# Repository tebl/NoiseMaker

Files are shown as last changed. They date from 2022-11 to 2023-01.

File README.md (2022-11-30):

# NoiseMaker
When I first started out with my somewhat weird hobby of working with seriously to extremely outdated computers, the first things to go were naturally the inevitably failing hard-drives that ended up being replaced by Compact Flash solutions. The second to go were the physical floppy disk drives, having been replaced by Gotek drives. The result, while enjoyable to use, were vintage computers that even the wife could even stand to listen to. Except... that's not good, they're supposed to go *whirr*, *click*, *whine* and rotate grinding gears at such a rate that your significant other simply won't just accept a room dedicated to your vintage computers, they should demand that you get started on building such a room!

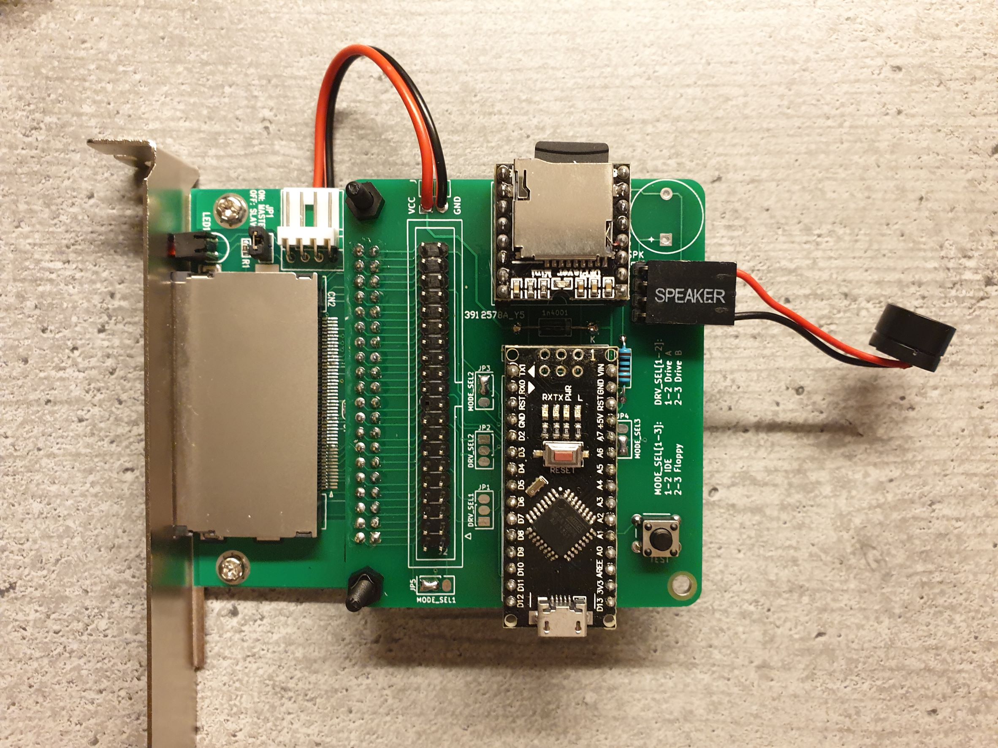
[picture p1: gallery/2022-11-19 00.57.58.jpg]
NoiseMaker Standard, with Compact Flash


Was I going back to the old failiure rate of old mechanical drives? Nope, I followed the tutorials and installed a buzzer kit on that Gotek. Was I happy with it? Not really. So I did what I tend to do, go on AliExpress and ordered a bucketload of Arduino-modules listed as capable of playing back sound files. The cheapest of the bunch by far, was the *MP3-TF-16P* - also commonly known as the *DFPlayer Mini*. The very next thing that I discovered was that I didn't really understand enough about the various signals used to communicate with floppy disk drives, so they all sat in box somewhere until someone created something called *HDD Clicker*. I saw the videos made about it, but I wanted more options and so I started tinkering with the modules again - especially with the realization of how simple an IDE-version could have been made if I had just started there instead.

The result was this project, an amalgamation of the cheapest hardware in an oversized package that somehow probably ends up costing several times more to build than the popular thing. I could certainly have gone for more compact or powerful options, but it was an excuse to use some  Arduino Nano boards "powered" by ATmega168, which I had accidentally ordered a couple of years ago and never got around to throwing out.

- [1> Modules](#1-modules)
  - [1.1> NoiseMaker Standard](#11-noisemaker-standard)
- [3> Acknowledgements](#3-acknowledgements)

# 1> Modules
The following modules have been provided as part of this project. While more modules may have been included as part of this repository, these are the ones that I have actually built and tested. As mentioned in the relevant license for this project - that's not a warranty, just an indication that it worked that one time I tried it with my particular setup.

| Module | Description |
| --- | --- |
| [NoiseMaker Standard](#11-noisemaker-standard) | Standard Arduino-based *NoiseMaker*, supporting 34-pin floppy and 40-pin IDE.

## 1.1> NoiseMaker Standard
This is the standard version of the *NoiseMaker*, created as a carrier board for both the *MP3-TF-16P* and an Arduino Nano. It can be built to work directly with IDE-devices, adding a female 40-pin header to the bottom of the card it can also be attached directly onto common *Compact Flash to IDE*-module. It can also be used in the "middle" of the cable, or just plugged into an unused part of the cable. The Arduino unfortunately doesn't have anywhere near the capability needed to actually interpret the communication between the devices, it is only responding to the same signal that your motherboard would normally read in order to light up your *HDD LED* (if you have one). 

Compact Flash

 Alternatively you can build the device for use with 34-pin floppy drive replacements such as the Gotek instead. Similarly as with the IDE-version, it can also be plugged into an unused connector on your cable or in-between your drive and motherboard. Note that since the 34-pin cables have a twist on it, you need to set the *DRV_SEL* to the opposite value if connecting it up by itself after the twist.

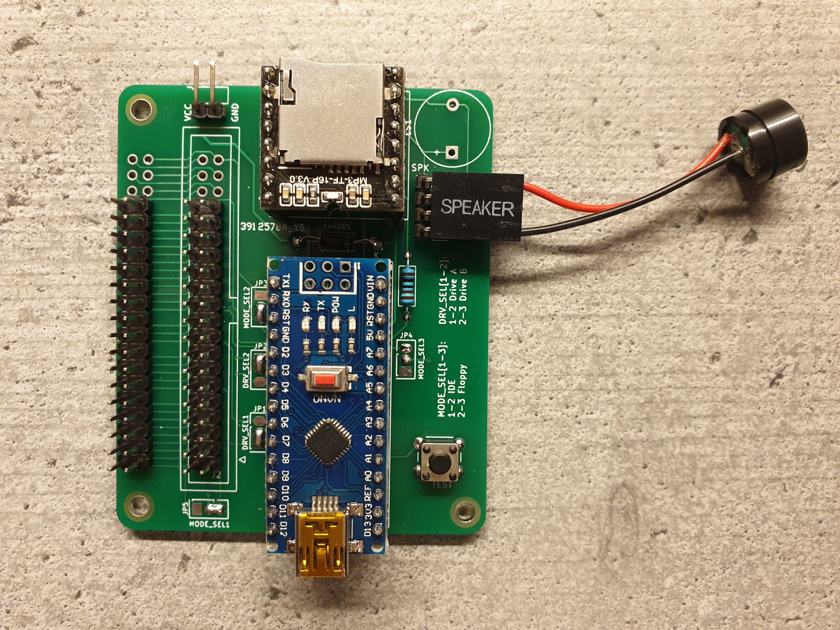
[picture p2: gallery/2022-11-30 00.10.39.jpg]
Floppy Interface


The documentation belonging to different variations of the standard NoiseMaker have been listed below, click the name for build documentation or follow the documentation links to jump to different sections within it. Ideally all of them should support being built as a NoiseMaker for either floppy or IDE, but not both at the same time (for that you will need two separate copies of the PCB).

| Module | Description | Documentation | Order |
| --- | --- | --- | --- |
| [NoiseMaker](https://github.com/tebl/NoiseMaker/tree/main/NoiseMaker) | Arduino Nano, MP3-TF-16P | [Documentation](https://github.com/tebl/NoiseMaker/tree/main/NoiseMaker), [BOM](https://github.com/tebl/NoiseMaker/blob/main/NoiseMaker/README.md#3-bom), [Setting it up](https://github.com/tebl/NoiseMaker/blob/main/documentation/setting_it_up.md), [Getting started](https://github.com/tebl/NoiseMaker/blob/main/documentation/getting_started.md) | PCBWay

# 3> Acknowledgements
Everything comes from something, in particular when it comes to most of my electronics projects. I mainly build things I would like to own, often doing a respin to fit my own particular style and preferences. As mentioned I originally started making a module for making noise when used with modern floppy drive replacements, but it was only with inspiration from seeing the *HDD Clicker* that I went back and actually finished building it.

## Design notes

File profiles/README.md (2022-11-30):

# 1> Profiles
The *NoiseMaker* simply plays audio files using a cheaply available module for Arduino, oftenly referred to as the *DFPlayer Mini* though the name *MP3-tf-16p* will probably be more correct. The Arduino sketch included as part of the *NoiseMaker* refers to different sets of audio files as *"profiles"* - the contents of the subdirectory called "sdcard" must be copied onto the SD-card used.

While I hope to make my own recordings to match my own hardware, a few profiles have been created using resources found online. As such they have their own terms for usage and so this file should include all of the information needed to comply with the license that they have been made available under. If you find something to be missing, let me know and I'll endevour to either update or have those specific files removed.

- Floppy
  - [01> Amiga Floppy Disk](#01-amiga-floppy)
- IDE
  - [10> IBM Deskstar 22GXP 7200](#old-hdds)
  - [11> WD Caviar BB 7200](#old-hdds)
  - [12> Seagate Medalist ST34321A 5400](#old-hdds)
  - [13> IBM UltraStar ES 5400](#old-hdds)
  - [14> Maxtor Atlas 10k](#old-hdds)

# 01> Amiga Floppy Disk
Modified versions of Amiga floppy drive sounds, the original audio files have been up for download as part of the [WinUAE](https://www.winuae.net/download/) installation.

# Old HDDs
User [Klerpp](https://freesound.org/people/Klerrp/) on freesound has created a pack of recordings of [old HDDs](https://freesound.org/people/Klerrp/packs/8850), this profile has been created with those recordings as a starting point. The files have been tweaked for length, volume and separated into separate files depending on what the HDD was doing at the time.

The files have been release under a [CC0 1.0-license](https://creativecommons.org/publicdomain/zero/1.0/), requiring no specific licensing steps beyond specifying that they come with no warranty of any kind - neither from its original creator or the NoiseMaker project.

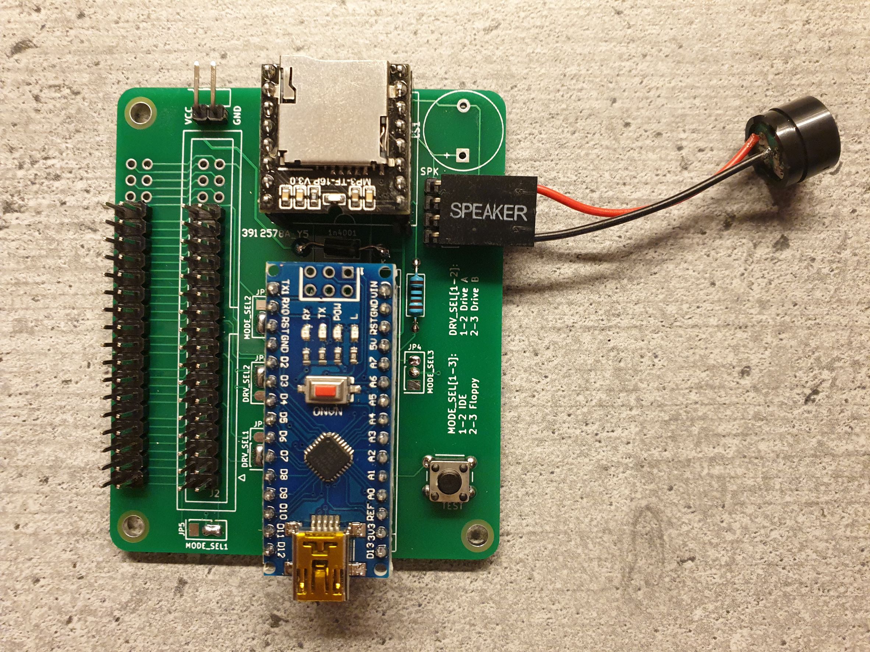
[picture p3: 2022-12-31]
gallery/2022-11-30 00.10.43.jpg

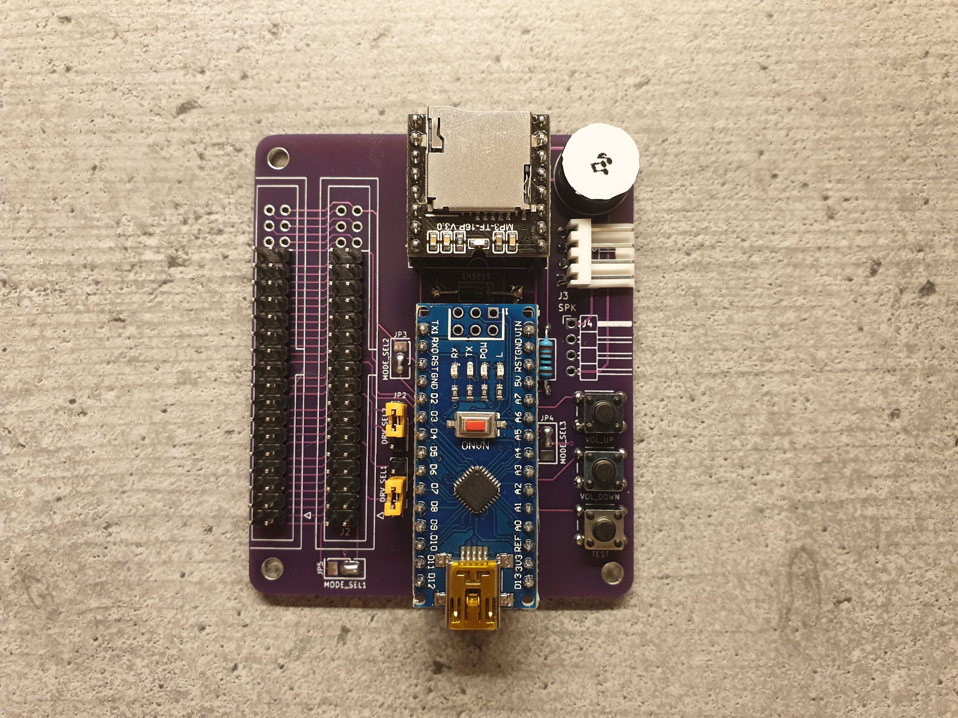
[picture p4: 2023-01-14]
gallery/2023-01-14 02.06.26.jpg

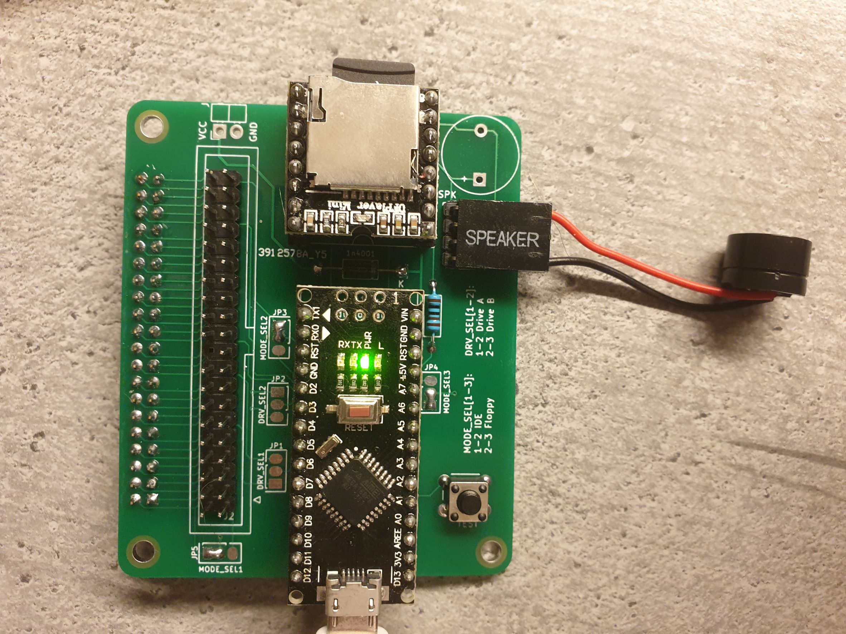
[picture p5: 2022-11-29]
gallery/2022-11-07 00.37.02.jpg

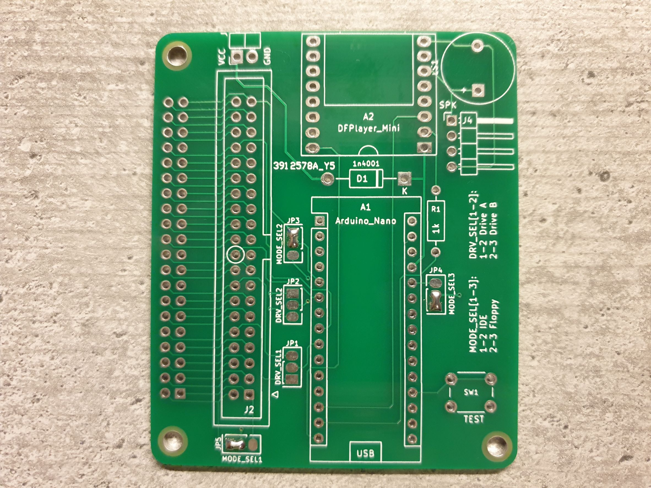
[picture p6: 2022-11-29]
gallery/2022-11-01 23.43.35.jpg

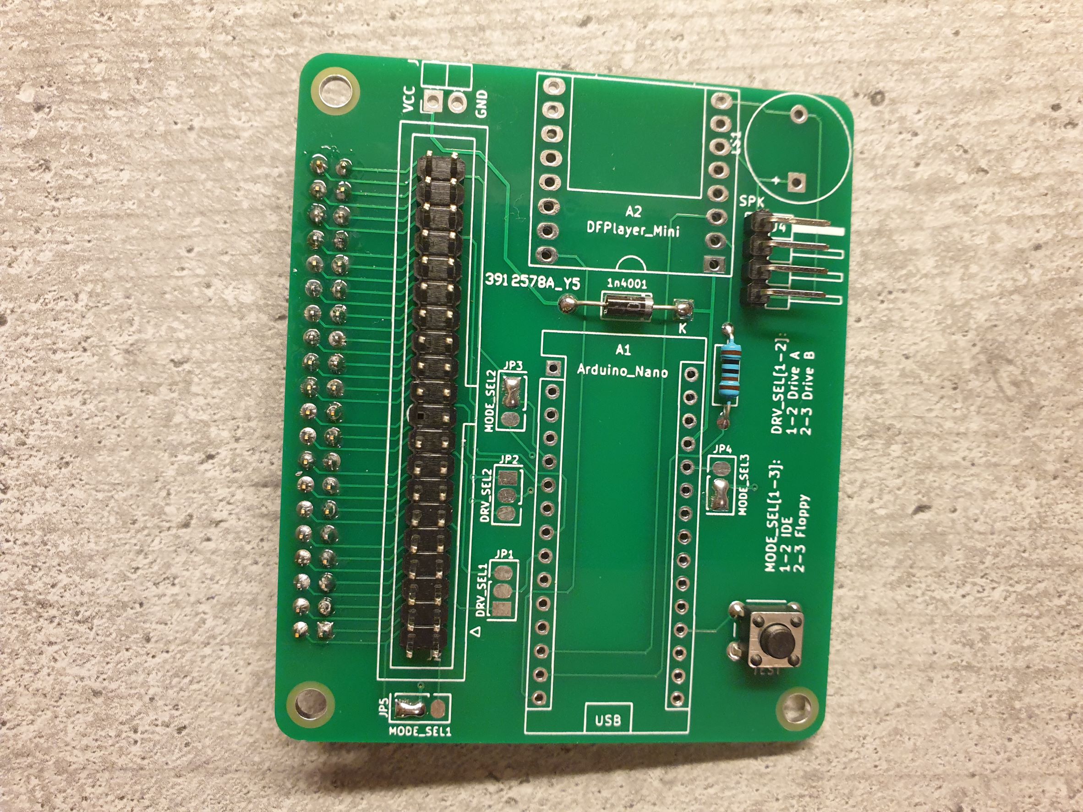
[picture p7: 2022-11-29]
gallery/2022-11-02 00.21.22.jpg

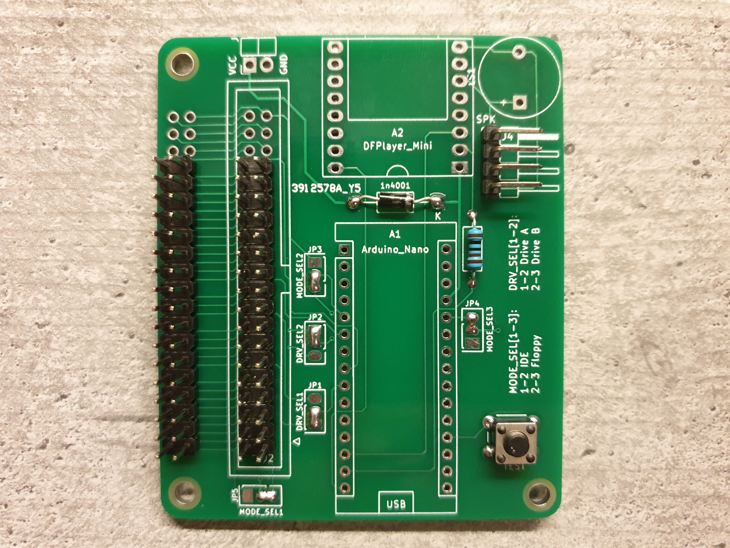
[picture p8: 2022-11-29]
gallery/2022-11-02 00.21.31.jpg

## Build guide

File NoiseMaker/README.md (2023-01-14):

# NoiseMaker Standard
The *NoiseMaker Standard*-version is really the first version I created for making noise when used with either 34-pin floppy drive replacements such as the Gotek - OR - the 40-pin IDE-replacements such as CF2IDE, SD2IDE etc. This document goes into building up a PCB for one of these, but not both at a time. For a more graceful introduction to what the *NoiseMaker* is meant to do, check out the main [documentation](https://github.com/tebl/NoiseMaker) before continuing.

- [1> Building the device](#1-building-the-device)
  - [1.1> Soldering it together](#11-soldering-it-together)
  - [1.2> IDE-version](#12-ide-version)
  - [1.3> Floppy-version](#13-floppy-version)
  - [1.4> Finishing touches](#14-finishing-touches)
- [2> Schematic](#2-schematic)
- [3> BOM](#3-bom)

# 1> Building the device
Building a device such as this assumes you have at least minor experience soldering things together, recommended is that you at the very least have access to a soldering station with adjustable temperature. If currently available, you should probably start with 60/40 rosin core solder as the lead-free alternatives tends to be a bit harder to work with.

With the requirements for basic equipment sorted, we need to talk a bit about what you want to achieve while building this project. The reason I ask is that as already mentioned, you need to pick between Floppy and IDE for each PCB you are building up, mainly because there are physical differences in how each of them connect to the your system. 

Now that you know what you want to build, we can get started on the most expensive step in any build process - shopping! So, head on over to the [BOM](#3-bom)-section for some information on what kind of components that you'll need. While I would have liked to give you specific part numbers for "reputable" electronic part suppliers, I can't afford to shop there so I usually make due with what I can find on sites such as ebay, AliExpress and any similar sites that sell cheap Chinese components. The downside to this is that I can't link to a part directly and expect it to stay listed, so you'll need to consider the description listed as a suggested *search term*.

## 1.1> Soldering it together
The construction of this unit should be fairly straight-forward, just take your time in order to make sure everything goes into place - more or less straight. I usually recommend starting by having a good look at the PCBs, then try to figure out where all of the listed components go and in which orientation they go in (all of this should be clearly marked on the silkscreen). There are no overlapping footprints and though doing it in the wrong order might make it a bit more fiddly to put together, there aren't really all that many issues you can run into as long as you're clear on which interface you're building it for (IDE or floppy). 

## 1.2> IDE-version
I've created a video that goes into whatever details you might need when assembling one for use with IDE, this one specificly was built to mount directly onto a common *Compact Flash*-adapter and for that reason I solder the power wires directly to it instead of using an additional floppy power connector from the systems PSU.

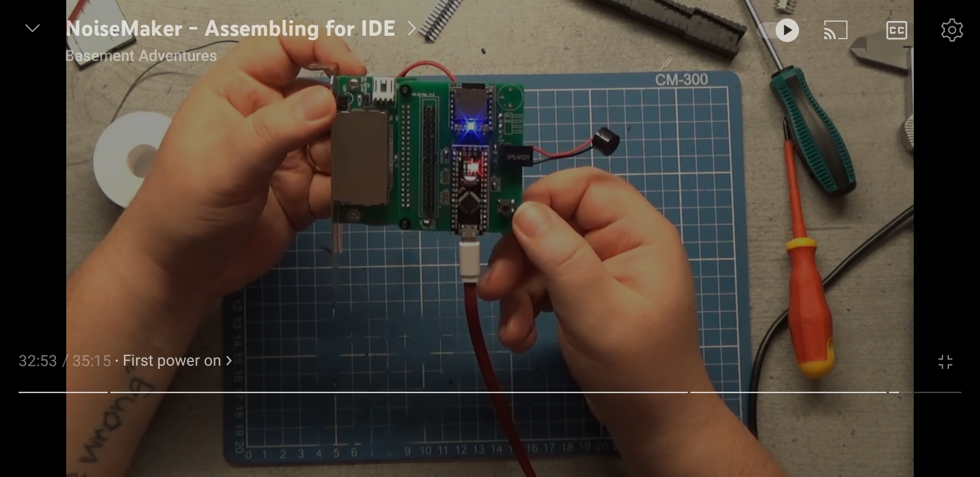
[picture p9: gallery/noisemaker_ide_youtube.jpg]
YouTube image (https://youtu.be/f5QjovpGp8M)


## 1.3> Floppy-version
For now I recommend that you check the build details for the IDE-version, it is mostly the same except for the use of 34-pin Interface.

## 1.4> Finishing touches
Unless one was provided to you by a kit-maker, you will more than likely not have the correct firmware installed on your Arduino Nano. The code you need can be found as part of this repository on the URL [software/arduino/NoiseMaker](https://github.com/tebl/NoiseMaker/tree/main/software/arduino/NoiseMaker), you will need to download a copy of this repository - this is done by using the green button on the [main page](https://github.com/tebl/NoiseMaker) of this repository. You will need to install a couple of libraries in order for the code to compile, the [README](https://github.com/tebl/NoiseMaker/blob/main/software/arduino/NoiseMaker/README.md) contains links to both of these though the preferable way of installing these is probably via your Arduino development environment. The files provided should be suitable for use with both Arduino Studio as well as PlatformIO.

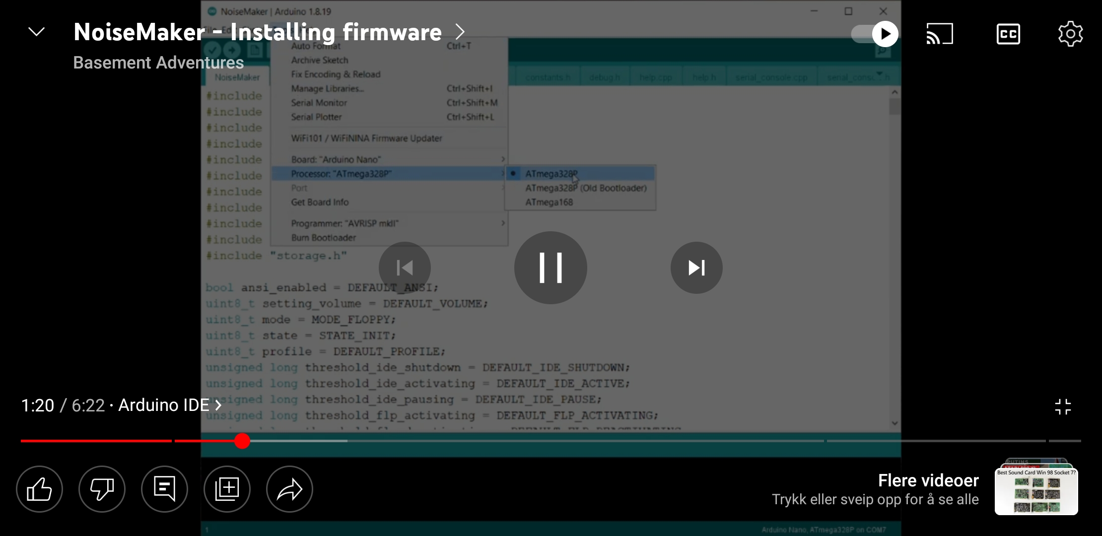
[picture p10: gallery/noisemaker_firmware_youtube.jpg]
YouTube image (https://www.youtube.com/watch?v=h_lniixsJmM)


For Arduino Studio, open the sketch and then select the board that you have (Arduino Nano of some kind). Install the two libraries from *Tools* --> *Manage libraries...* - search for and install the two listed as *ezbutton* as well as *DFRobotDFPlayerMini*. Check that the code now compiles, select the serial port corresponding to your module and upload the sketch.

PlatformIO should handle dependencies somewhat automatically, though I find that in practice we need to run a command for it to happen. Open up a new PlatformIO Terminal (not PowerShell, it's probably the last icon on your bottom toolbar), then run the command *"pio pkg install"*, and it should download and install the latest version of the libraries needed. Ensure that the environment selected on the bottom toolbar corresponds to the board you are using, you may need to edit *platformio.ini* if neither of the combinations is correct for you. Compile and upload the code.

Using a serial terminal connected to the Arduino Nano, you may configure the device according to your preferences. It is recommended to use an ATmega328-based Arduino Nano when you are familiarizing yourself with the commands, as among other commands the *help* command is not available on the ATmega168. When satisfied with any changes, enter the command *save* to store them permanently to the onboard EEPROM. For more detailed information as well as serving as a reference when used with ATmega168, see [Serial Interface](https://github.com/tebl/NoiseMaker/blob/main/documentation/serial_interface.md).

# 2> Schematic
The supplied KiCad files should be sufficient as both a schematic and as a  starting point for ordering PCBs (basically you could just zip the contents of the export folder and upload that on a fabrication site), the schematic is also available in [PDF-format](https://github.com/tebl/NoiseMaker/tree/main/documentation/schematic) and this is what you'll need to print and work your way through this things don't work as expected after assembly.

# 3> BOM
Most parts should be easy to get a hold of from your favourite local electronic component shop, but given that I don't have access to such shops where I live so everything was based on whatever I could get cheapest from eBay/AliExpress (free shipping, but plan on waiting 3-4 weeks for delivery). Components in parenthesis can be considered optional for features beyond the more basic functionality, but where's the fun in that? You probably want the complete package.

| Reference | Item | Count | Order  |
| --- | --- | ----- | --- |
| NoiseMaker Standard | Fabricate using Gerber files | 1 | [PCBWay](https://www.pcbway.com/project/shareproject/NoiseMaker_IDE_Floppy_8a4ab037.html)
| A1 * | Arduino Nano (328, 168 with less features) | 1 |
| A2 * | MP3-TF-16P (also known as DFPlayer Mini) | 1 |
| D1 | 1N5819 (DO-41), 1N4001 if you don't have one available | 1 |
| J1 ** | 2x20pin female header, 2x20pin male header or 2x17pin male header | 1 |
| J2 ** | 2x20pin male header or 2x17pin male header | 1 |
| J3 *** | JVC Mini 4P, right-angle flat power connector for floppy | 1 |
| J4 | 4pin breakable right-angle header | (1)|
| JP1, JP2 | 3pin straight pin header | 2 |
| | Jumper cap | 2 |
| LS1 | Passive buzzer (7.62mm pin spacing) | (1)|
| R1 | 1k Ohm resistor | 1 |
| SW1-SW3 | 6x6mm momentary button | (3)|

*) Both of the modules will be soldered to the PCB with some straight male headers in between, when assembling the first unit it is recommend that you assemble it with female pin headers on the board so that modules can be moved around until happy with the results.

**) The type of header used here depends on what the board will be used as, 2x16pin are for floppy while 2x20pin are for IDE.

***) When installed directly on top of a Compact Flash adapter you can opt to wire it directly to the adapter. If you can't find the connector, it might be easier to find a floppy power splitter cable, cut and solder on the wires from that.

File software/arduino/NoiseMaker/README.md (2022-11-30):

# NoiseMaker

The functionality of the *NoiseMaker* has been realized using what for all purposes can be considered the least common denominator when it comes to MCUs, the standard ATmega328-based *Arduino Nano*. Due to an accidental order a couple years back I ended up with a handful of boards even more limited than these ones, based on the ATmega168 instead - offering half of the RAM and flash space expected - in order to get some usage out of them there is the option of using these lower capacity chips as well. This does however come at the cost of some nice-to-have features, but beyond being slightly less configurable on-the-fly using the serial interface - you should be able to enjoy it just the same once things are properly set up.

Consider editing *settings.h* to your liking instead of relying on run-time configuration, if you already have a preference for the values you want to use in the end. For either version of board, just make sure that you've correctly specified the chip used - before compiling the code.

## Libraries

While the installation of libraries should be handled automatically when using PlatformIO from within Visual Studio Code, but I recognize that many will simply want to get the code onto the board while using the standard *Arduino IDE* instead. In that case you may need to install libraries manually, the ones that are currently needed are as follows:

- [DFRobotDFPlayerMini](https://github.com/DFRobot/DFRobotDFPlayerMini)
- [ezButton](https://github.com/ArduinoGetStarted/button)

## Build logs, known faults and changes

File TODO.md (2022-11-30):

# TODO
- NoiseMaker Standard
- NoiseMaker Mini
  - Create a smaller version of the board, with wire-pads instead of full 34-pin or 40-pin connectors.

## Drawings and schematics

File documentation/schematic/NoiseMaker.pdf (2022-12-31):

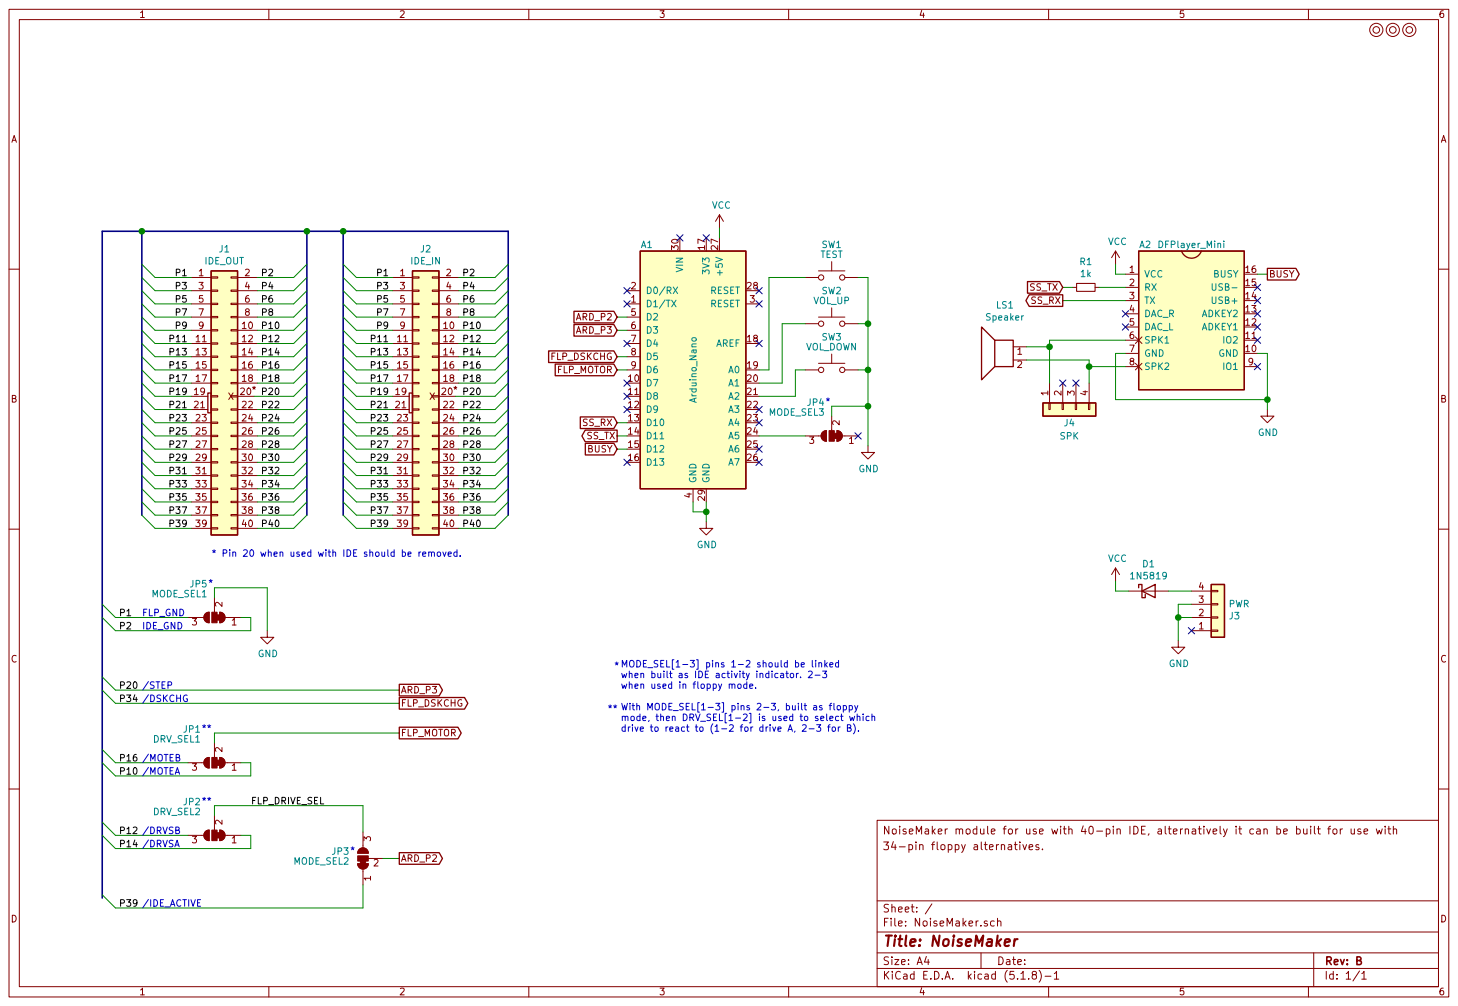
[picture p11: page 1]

* Pin 20 when used with IDE should be removed.

* MODE_SEL[1-3] pins 1-2 should be linked
when built as IDE activity indicator. 2-3
when used in floppy mode.

drive to react to (1-2 for drive A, 2-3 for B). **
mode, then DRV_SEL[1-2] is used to select which

NoiseMaker module for use with 40-pin IDE, alternatively it can be built for use with
Id: 1/1 Title: NoiseMaker File: NoiseMaker.sch Sheet: / 34-pin floppy alternatives.

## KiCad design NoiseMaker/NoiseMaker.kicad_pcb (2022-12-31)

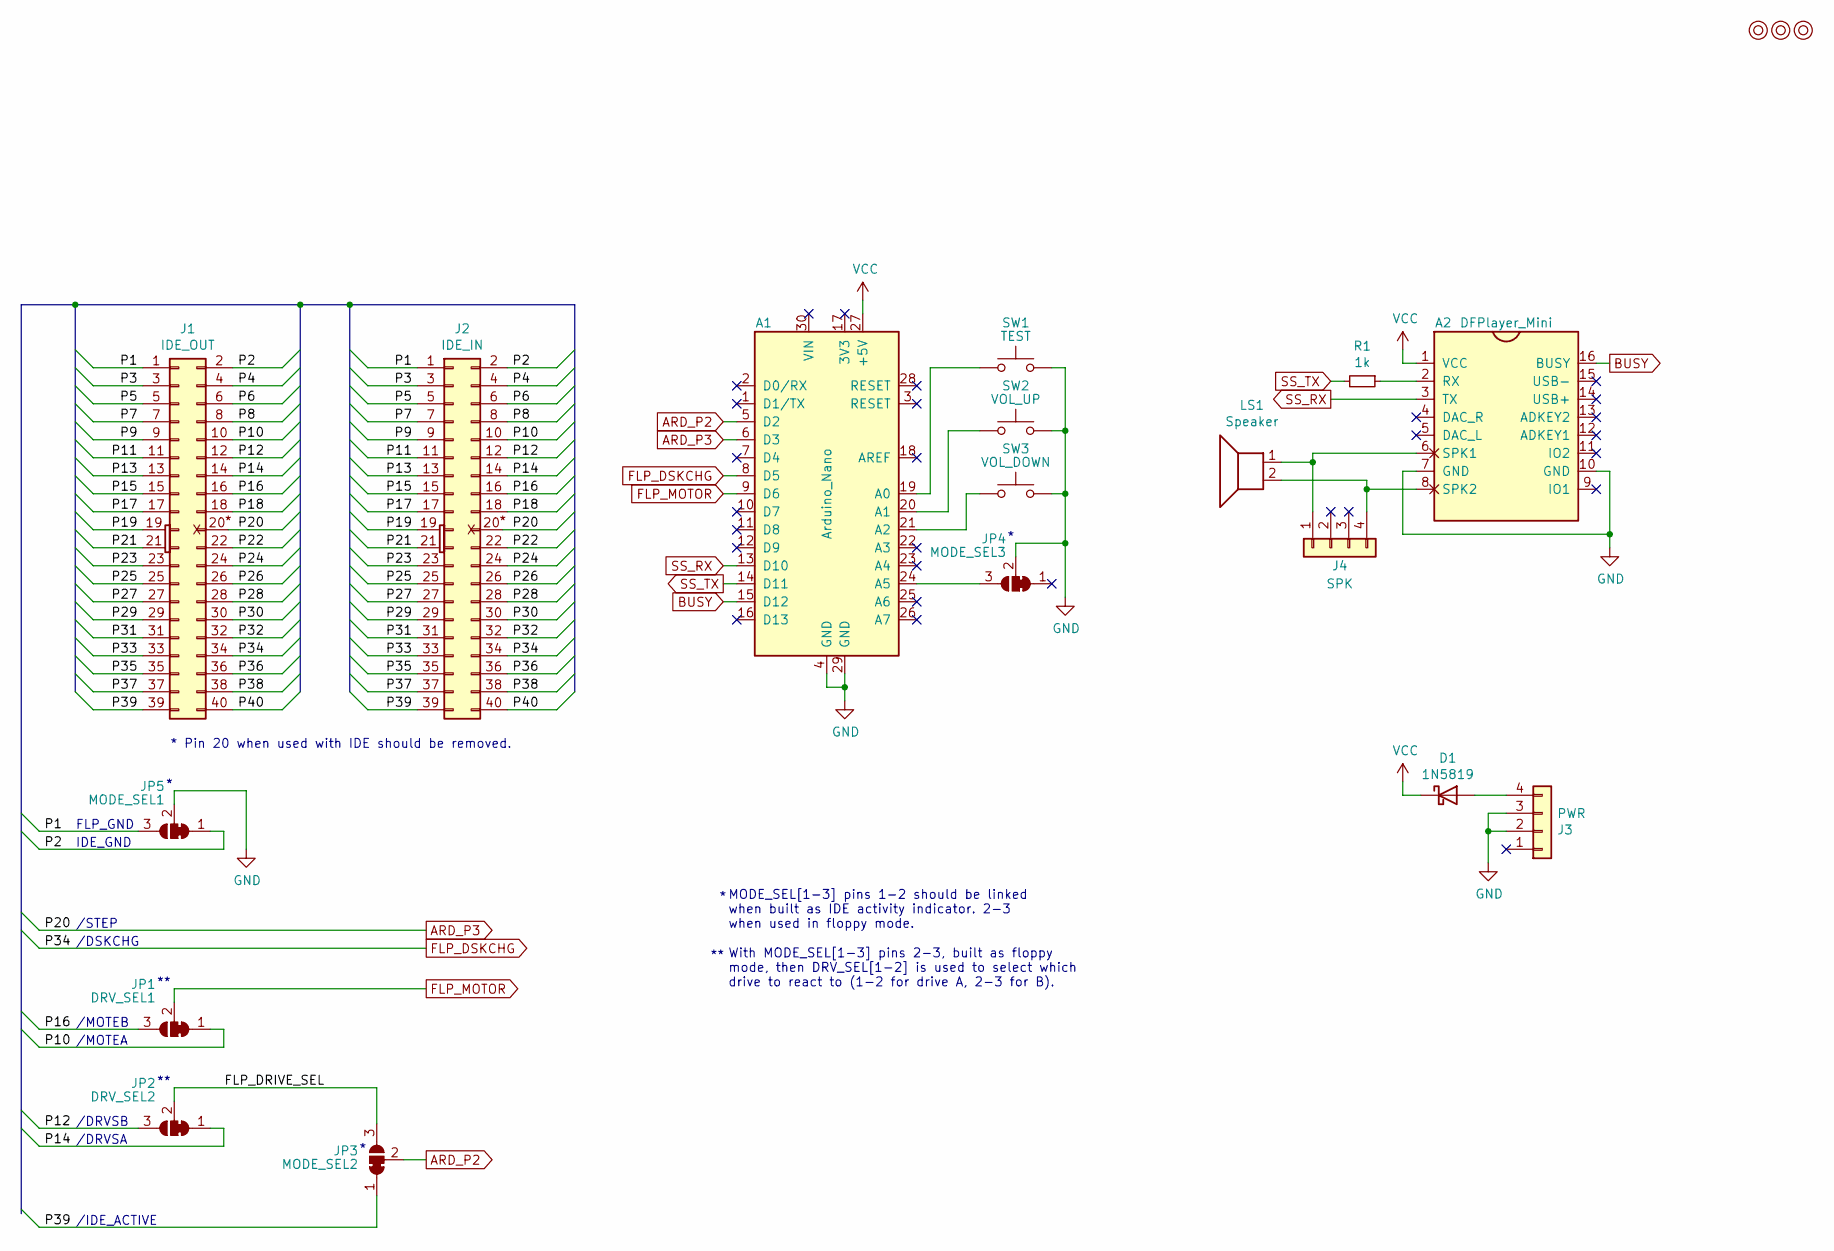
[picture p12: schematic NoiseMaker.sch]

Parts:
A1: Arduino_Nano
A2: DFPlayer_Mini
D1: 1N5819; D_DO-41_SOD81_P12.70mm_Horizontal
J1: IDE_OUT; PinSocket_2x20_P2.54mm_Vertical
J2: IDE_IN; IDC-Header_2x20_P2.54mm_Vertical
J3: PWR; Molex_KK-254_1x04_P2.54mm_Horizontal
J4: SPK; PinHeader_1x04_P2.54mm_Horizontal
JP1: DRV_SEL1; PinHeader_1x03_P2.54mm_Vertical
JP2: DRV_SEL2; PinHeader_1x03_P2.54mm_Vertical
JP3: MODE_SEL2; select2
JP4: MODE_SEL3; select2
JP5: MODE_SEL1; select2
LS1: Speaker; Buzzer_12x9.5RM7.6
M1, M2, M3: Mounting; M3_pin
R1: 1k; R_Axial_DIN0207_L6.3mm_D2.5mm_P10.16mm_Horizontal
SW1: TEST; SW_PUSH_6mm
SW2: VOL_UP; SW_PUSH_6mm
SW3: VOL_DOWN; SW_PUSH_6mm

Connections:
/FLP_DRIVE_SEL: JP2.2 (C), JP3.3 (B)
/P1: J1.1, J2.1, JP5.3 (B)
/P2: J1.2, J2.2, JP5.1 (A)
/P3: J1.3, J2.3
/P4: J1.4, J2.4
/P5: J1.5, J2.5
/P6: J1.6, J2.6
/P7: J1.7, J2.7
/P8: J1.8, J2.8
/P9: J1.9, J2.9
/P10: J1.10, J2.10, JP1.1 (A)
/P11: J1.11, J2.11
/P12: J1.12, J2.12, JP2.3 (B)
/P13: J1.13, J2.13
/P14: J1.14, J2.14, JP2.1 (A)
/P15: J1.15, J2.15
/P16: J1.16, J2.16, JP1.3 (B)
/P17: J1.17, J2.17
/P18: J1.18, J2.18
/P19: J1.19, J2.19
/P21: J1.21, J2.21
/P22: J1.22, J2.22
/P23: J1.23, J2.23
/P24: J1.24, J2.24
/P25: J1.25, J2.25
/P26: J1.26, J2.26
/P27: J1.27, J2.27
/P28: J1.28, J2.28
/P29: J1.29, J2.29
/P30: J1.30, J2.30
/P31: J1.31, J2.31
/P32: J1.32, J2.32
/P33: J1.33, J2.33
/P35: J1.35, J2.35
/P36: J1.36, J2.36
/P37: J1.37, J2.37
/P38: J1.38, J2.38
/P39: J1.39, J2.39, JP3.1 (A)
/P40: J1.40, J2.40
ARD_P2: A1.5 (D2), JP3.2 (C)
ARD_P3: A1.6 (D3), J1.20, J2.20
BUSY: A1.15 (D12), A2.16 (BUSY)
FLP_DSKCHG: A1.8 (D5), J1.34, J2.34
FLP_MOTOR: A1.9 (D6), JP1.2 (C)
GND: A1.4 (GND), A1.29 (GND), A2.7 (GND), A2.10 (GND), J3.2, J3.3, JP4.2 (C), JP5.2 (C), SW1.2, SW2.2, SW3.2
unnamed: A1.19 (A0), SW1.1
unnamed: A1.20 (A1), SW2.1
unnamed: A1.21 (A2), SW3.1
unnamed: A1.24 (A5), JP4.3 (B)
unnamed: A2.2 (RX), R1.1
unnamed: A2.6 (SPK1), J4.1, LS1.1
unnamed: A2.8 (SPK2), J4.4, LS1.2
unnamed: D1.2 (A), J3.4
SS_RX: A1.13 (D10), A2.3 (TX)
SS_TX: A1.14 (D11), R1.2
VCC: A1.27 (+5V), A2.1 (VCC), D1.1 (K)

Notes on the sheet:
/DRVSA
/DRVSB
/MOTEA
/MOTEB
/IDE_ACTIVE
/STEP
/DSKCHG
* Pin 20 when used with IDE should be removed.
IDE_GND
FLP_GND
MODE_SEL[1-3] pins 1-2 should be linked when built as IDE activity indicator. 2-3 when used in floppy mode.
With MODE_SEL[1-3] pins 2-3, built as floppy mode, then DRV_SEL[1-2] is used to select which drive to react to (1-2 for drive A, 2-3 for B).

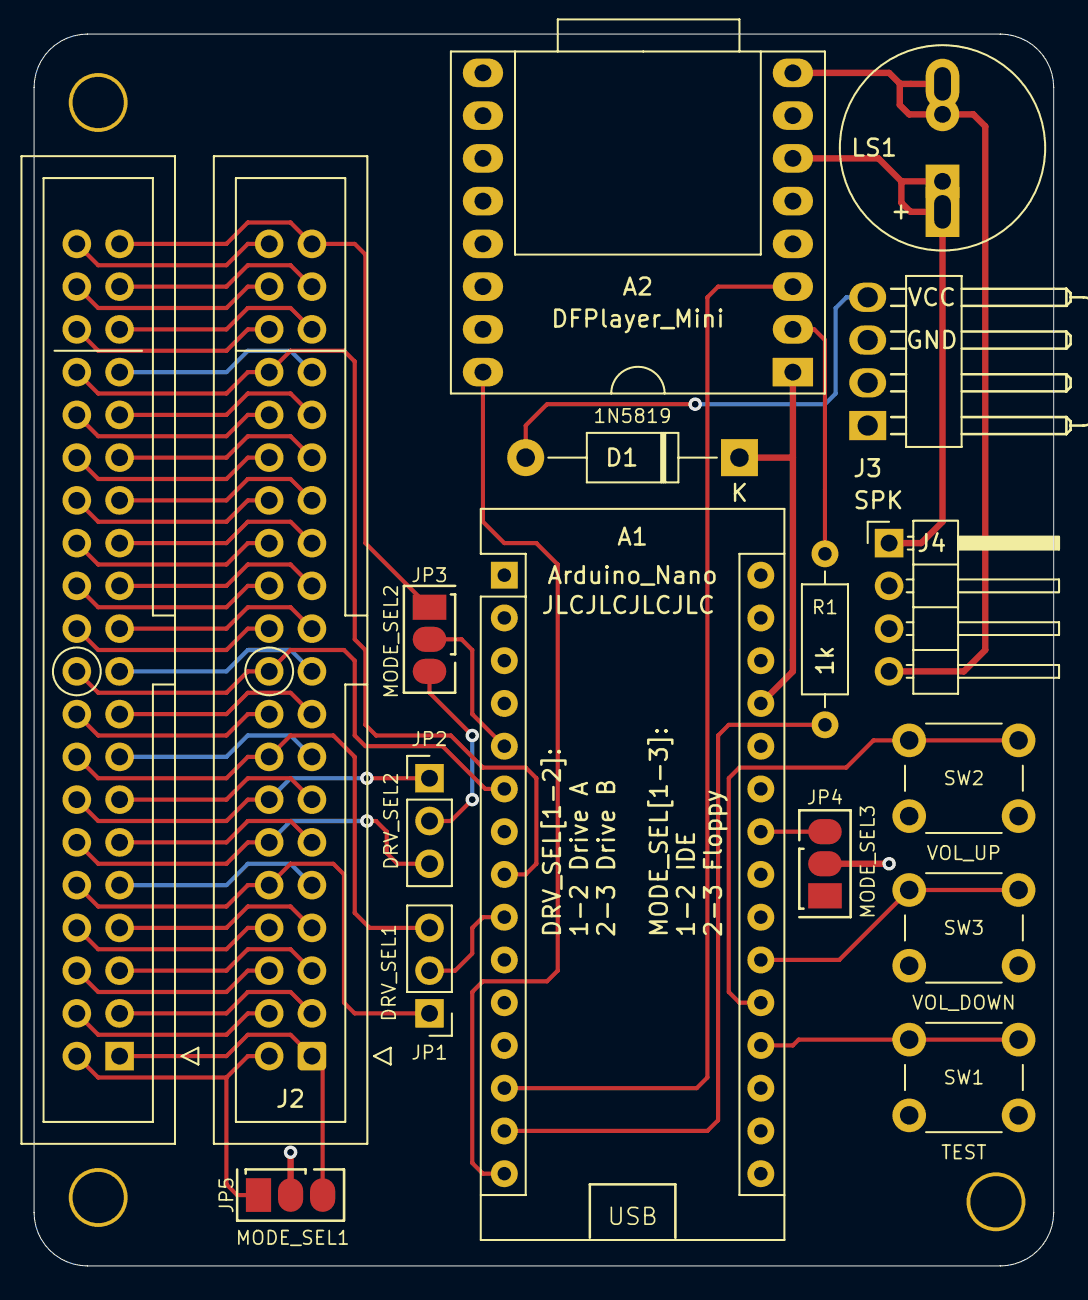
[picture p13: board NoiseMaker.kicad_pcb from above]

Board: 2 copper layers, 60.6 x 73.2 mm, 20 parts (1 on the bottom side), 56 nets.

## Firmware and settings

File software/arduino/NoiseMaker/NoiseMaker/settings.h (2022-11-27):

#pragma once
#include "constants.h"
// #define DEBUG
// #define DEBUG_VERBOSE
// #define DEBUG_OFFLINE

#define DEFAULT_IDE_SHUTDOWN TEN_MINUTES
#define DEFAULT_IDE_ACTIVE 100
#define DEFAULT_IDE_PAUSE 250
#define DEFAULT_FLP_ACTIVATING 500
#define DEFAULT_FLP_DEACTIVATING 750

#define DEFAULT_VOLUME 15
#define DEFAULT_ANSI false
#define DEFAULT_PROFILE 0

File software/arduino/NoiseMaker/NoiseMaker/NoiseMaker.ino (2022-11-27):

#include <Arduino.h>
#include <ezButton.h>
#include <SoftwareSerial.h>
#include <DFRobotDFPlayerMini.h>
#include "constants.h"
#include "settings.h"
#include "debug.h"
#include "serial_console.h"
#include "commands.h"
#include "ansi.h"
#include "storage.h"

bool ansi_enabled = DEFAULT_ANSI;
uint8_t setting_volume = DEFAULT_VOLUME;
uint8_t mode = MODE_FLOPPY;
uint8_t state = STATE_INIT;
uint8_t profile = DEFAULT_PROFILE;
unsigned long threshold_ide_shutdown = DEFAULT_IDE_SHUTDOWN;
unsigned long threshold_ide_activating = DEFAULT_IDE_ACTIVE;
unsigned long threshold_ide_pausing = DEFAULT_IDE_PAUSE;
unsigned long threshold_flp_activating = DEFAULT_FLP_ACTIVATING;
unsigned long threshold_flp_deactivating = DEFAULT_FLP_DEACTIVATING;

SoftwareSerial dfplayer_serial(DFPlayer_RX, DFPlayer_TX);
DFRobotDFPlayerMini dfplayer;
ezButton vol_up(PIN_VOL_UP);
ezButton vol_down(PIN_VOL_DOWN);

volatile unsigned long last_activity = 0;
bool last_motor_on = false;
uint8_t last_error;
bool replay = false;

void play_flp_startup() {
  dfplayer.playFolder(OFFSET_FLOPPY + profile, SOUND_FLP_STARTUP);
}

void play_flp_spin() {
  dfplayer.playFolder(OFFSET_FLOPPY + profile, SOUND_FLP_SPIN);
}

void play_flp_snatch() {
  dfplayer.playFolder(OFFSET_FLOPPY + profile, SOUND_FLP_SNATCH);
}

void play_flp_click() {
  dfplayer.advertise(OFFSET_FLOPPY + profile);
}

void flp_interrupt_step() {
  // if (digitalRead(PIN_FLP_DRIVE_SEL) == LOW) {
    last_activity = millis();
  // }
}

void setup_floppy() {
  uint8_t mode = INPUT;
  #ifdef DEBUG_OFFLINE
    mode = INPUT_PULLUP;
  #endif
  pinMode(PIN_FLP_DRIVE_SEL, mode);
  pinMode(PIN_FLP_STEP, mode);
  pinMode(PIN_FLP_DISK_CHANGE, mode);
  pinMode(PIN_FLP_MOTOR_EN, mode);

  play_flp_startup();
  attachInterrupt(digitalPinToInterrupt(PIN_FLP_STEP), flp_interrupt_step, FALLING);
}

void play_ide_startup() {
  dfplayer.playFolder(OFFSET_IDE + profile, SOUND_IDE_STARTUP);
}

void play_ide_active() {
  dfplayer.playFolder(OFFSET_IDE + profile, SOUND_IDE_ACTIVE);
}

void play_ide_shutdown() {
  dfplayer.playFolder(OFFSET_IDE + profile, SOUND_IDE_SHUTDOWN);
}

void ide_interrupt() {
  last_activity = millis();
}

void setup_ide() {
  uint8_t mode = INPUT;
  #ifdef DEBUG_OFFLINE
    mode = INPUT_PULLUP;
  #endif
  pinMode(PIN_IDE_ACTIVE, mode);

  play_ide_startup();
  attachInterrupt(digitalPinToInterrupt(PIN_IDE_ACTIVE), ide_interrupt, FALLING);
}

void loop_floppy() {
  switch (state) {
    /* Waiting for startup sound to finish */
    case STATE_INIT:
      while (dfplayer.available()) {
        last_error = dfplayer.readType(); 
        if (last_error == DFPlayerPlayFinished) {
          delay(100);
          DEBUG_PRINTLN(F("set idle"));
          state = STATE_FLP_IDLE;
        } else unknown_error(last_error, dfplayer.read());
      }
      break;

    /* Waiting for activity */
    case STATE_FLP_IDLE:
      while (digitalRead(DFPlayer_BUSY) == LOW) DEBUG_SPINLOCK('-');
      if (digitalRead(PIN_FLP_MOTOR_EN) == LOW) {
        DEBUG_PRINTLN(F("motor on"));
        state = STATE_FLP_SPINNING;
        play_flp_spin();
      }
      break;
    
    /* Motor is spinning, wait for steps */
    case STATE_FLP_SPINNING:
      replay = false;
      if (digitalRead(PIN_FLP_MOTOR_EN) == HIGH) {
        DEBUG_PRINTLN(F("motor off"));
        state = STATE_FLP_IDLE;
        dfplayer.stop();
        while (digitalRead(DFPlayer_BUSY) == LOW) DEBUG_SPINLOCK('.');
      } else {
        while (dfplayer.available()) {
          last_error = dfplayer.readType(); 
          if (last_error == DFPlayerPlayFinished) {
            replay = true;
          } else unknown_error(last_error, dfplayer.read());
        }

        if (replay) {
            DEBUG_PRINTLN(F("replay spin"));
            play_flp_spin();
            delay(100);
            while (digitalRead(DFPlayer_BUSY) == HIGH) DEBUG_SPINLOCK('*');;
        } else {
          if (last_activity > 0 && ((millis() - last_activity) < threshold_flp_activating)) {
            DEBUG_PRINTLN(F("activating"));
            state = STATE_FLP_ACTIVE;
            play_flp_click();
            while (digitalRead(DFPlayer_BUSY) == HIGH) DEBUG_SPINLOCK('+');;
          }
        }
      }
      break;
    
    /* Motor is on, steps recently been taken */
    case STATE_FLP_ACTIVE:
      replay = false;
      if ((millis() - last_activity) > threshold_flp_deactivating) {
        DEBUG_PRINTLN(F("deactivating"));
        state = STATE_FLP_SPINNING;
        dfplayer.stopAdvertise();
        delay(200);
      } else {
        while (dfplayer.available()) {
          last_error = dfplayer.readType(); 
          if (last_error == DFPlayerPlayFinished) {
            replay = true;
          } else unknown_error(last_error, dfplayer.read());
        }

        if (replay) {
            DEBUG_PRINTLN(F("replay click"));
            play_flp_click();
            delay(200);
            while (digitalRead(DFPlayer_BUSY) == HIGH) DEBUG_SPINLOCK('/');;
        }
      }
      break;
  }
}

void setup() {
  dfplayer_serial.begin(BAUD_RATE_9600);
  process_serial_init();
  pinMode(PIN_TEST, INPUT_PULLUP);
  vol_up.setDebounceTime(50);
  vol_down.setDebounceTime(50);
  pinMode(PIN_MODE_SEL, INPUT_PULLUP);
  digitalWrite(PIN_LED, LOW);
  pinMode(PIN_LED, OUTPUT);
  pinMode(DFPlayer_BUSY, INPUT);

  ansi_default();
  Serial.print(F("Initializing "));
  ansi_highlight();
  print_version();
  ansi_default();

  Serial.print(F("Initializing DFPlayer ... "));
  if (!dfplayer.begin(dfplayer_serial, true, false)) {
    ansi_error();
    Serial.println(F("failed!"));
    Serial.println(F("Check SD-card!"));
    while(true) delay(0);
  };
  ansi_highlight_ln(F("done!"));

  Serial.print(F("Configured mode is... "));
  if (digitalRead(PIN_MODE_SEL) == LOW) {
    mode = MODE_FLOPPY;
    ansi_highlight_ln(F("floppy!"));
  } else {
    mode = MODE_IDE;
    ansi_highlight_ln(F("IDE!"));
  }

  restore_settings();

  if (mode == MODE_FLOPPY) setup_floppy();
  else setup_ide();
}

void loop_ide() {
  switch (state) {
    /* Waiting for startup sound to finish */
    case STATE_INIT:
      while (dfplayer.available()) {
        last_error = dfplayer.readType(); 
        if (last_error == DFPlayerPlayFinished) {
          delay(100);
          DEBUG_PRINTLN(F("set idle"));
          state = STATE_IDE_IDLE;
        } else unknown_error(last_error, dfplayer.read());
      }
      break;

    /* Waiting for activity */
    case STATE_IDE_IDLE:
      while (digitalRead(DFPlayer_BUSY) == LOW);
      if (last_activity > 0 && ((millis() - last_activity) < threshold_ide_activating)) {
        DEBUG_PRINTLN(F("activating"));
        state = STATE_IDE_ACTIVE;
        play_ide_active();
      }
      break;

    case STATE_IDE_ACTIVE:
      /* Check for activity timeout */
      replay = false;
      if ((millis() - last_activity) > threshold_ide_pausing) {
        DEBUG_PRINTLN(F("pausing"));
        state = STATE_IDE_PAUSED;
        dfplayer.pause();
        while (digitalRead(DFPlayer_BUSY) == LOW);
      } else {
        while (dfplayer.available()) {
          last_error = dfplayer.readType(); 
          if (last_error == DFPlayerPlayFinished) {
            delay(100);
            replay = true;
          } else unknown_error(last_error, dfplayer.read());
        }

        if (replay) {
            DEBUG_PRINTLN(F("replay"));
            play_ide_active();
            while (digitalRead(DFPlayer_BUSY) == HIGH);
        }
      }
      break;

    case STATE_IDE_PAUSED:
      if (last_activity > 0) {
        /* Check if we now see activity again */
        if ((millis() - last_activity) < threshold_ide_activating) {
          DEBUG_PRINTLN(F("resuming"));
          state = STATE_IDE_ACTIVE;
          dfplayer.start();
          while (digitalRead(DFPlayer_BUSY) == HIGH);
        }

        /* Check for shutdown. We can't actually know this due to only seeing
         * HDD-busy instead of the registers, so we just play the sound make
         * sure that we're ready to continue doing activity sounds right after
         * (instead of doing another startup).
         */
        if (threshold_ide_shutdown > 0 && (millis() - last_activity) > threshold_ide_shutdown) {
          DEBUG_PRINTLN(F("shutdown"));
          play_ide_shutdown();
          state = STATE_INIT;
          while (digitalRead(DFPlayer_BUSY) == HIGH);
        }
      }
      break;

    default:
      break;
  }
}

void unknown_error(uint8_t type, int value) {
  #if defined(__AVR_ATmega328P__)
  switch (type) {
    case TimeOut:
      ansi_error_ln(F("Time Out!"));
      break;
    case WrongStack:
      ansi_error_ln(F("Stack Wrong!"));
      break;
    case DFPlayerCardInserted:
      ansi_notice_ln(F("Card Inserted!"));
      break;
    case DFPlayerCardRemoved:
      ansi_error_ln(F("Card Removed!"));
      break;
    case DFPlayerCardOnline:
      ansi_notice_ln(F("Card Online!"));
      break;
    case DFPlayerPlayFinished:
      ansi_notice_ln(F("Track finished!"));
      break;
    case DFPlayerError:
      ansi_error();
      Serial.print(F("DFPlayerError: "));
      switch (value) {
        case Busy:
          Serial.println(F("Card not found"));
          break;
        case Sleeping:
          Serial.println(F("Sleeping"));
          break;
        case SerialWrongStack:
          Serial.println(F("Get Wrong Stack"));
          break;
        case CheckSumNotMatch:
          Serial.println(F("Check Sum Not Match"));
          break;
        case FileIndexOut:
          Serial.println(F("File Index Out of Bound"));
          break;
        case FileMismatch:
          Serial.println(F("Cannot Find File"));
          break;
        case Advertise:
          Serial.println(F("In Advertise"));
          break;
        default:
          break;
      }
      ansi_default();
      break;
    default:
      break;
  }
  #else
  switch (type) {
    case TimeOut:
    case WrongStack:
    case DFPlayerCardRemoved:
    case DFPlayerError:
      ansi_error();
      Serial.print((__FlashStringHelper*) STR_ERROR_DFPLAYER);
      if (type == DFPlayerError) {
        Serial.print(type);
        Serial.print(' ');
        Serial.print(value);
      } else Serial.println(type);
      ansi_default();
      break;

    case DFPlayerPlayFinished:
    case DFPlayerCardOnline:
    case DFPlayerCardInserted:
      ansi_notice();
      Serial.print((__FlashStringHelper*) STR_ERROR_DFPLAYER);
      Serial.println(type);
      ansi_default();
      break;

    default:
      break;
  }
  #endif
}

void process_switches() {
  vol_up.loop();
  vol_down.loop();

  if (digitalRead(PIN_TEST) == LOW) {
    last_activity = millis();
  }

  if (vol_up.isPressed()) {
    volume_up();
  }

  if (vol_down.isPressed()) {
    volume_down();
  }
}

void loop() {
  process_serial();
  process_switches();
  digitalWrite(PIN_LED, !digitalRead(DFPlayer_BUSY));

  if (mode == MODE_FLOPPY) loop_floppy();
  else loop_ide();
}

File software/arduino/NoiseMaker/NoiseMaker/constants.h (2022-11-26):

#pragma once

/* Magic numbers */
#define BAUD_RATE_115200 115200
#define BAUD_RATE_38400 38400
#define BAUD_RATE_19200 19200
#define BAUD_RATE_9600 9600
#define BAUD_RATE_4800 4800
#define BAUD_RATE BAUD_RATE_115200

#define TERMINAL_COLS 80

#define MODE_IDE 0
#define MODE_FLOPPY 1

#define STATE_INIT 0
#define STATE_FLP_IDLE 1
#define STATE_FLP_SPINNING 2
#define STATE_FLP_ACTIVE 3

#define STATE_IDE_IDLE 10
#define STATE_IDE_ACTIVE 11
#define STATE_IDE_PAUSED 12

#define SOUND_IDE_STARTUP 1
#define SOUND_IDE_ACTIVE 2
#define SOUND_IDE_SHUTDOWN 3
#define SOUND_FLP_STARTUP 1
#define SOUND_FLP_SPIN 2
#define SOUND_FLP_SNATCH 3
#define SOUND_FLP_CLICK 4

#define ONE_MINUTE 60000L
#define TEN_MINUTES 600000L
#define FIFTEEN_MINUTES 900000L

#define OFFSET_FLOPPY 1
#define OFFSET_IDE 10

/* Pin definitions */
#define DFPlayer_TX 11
#define DFPlayer_RX 10
#define DFPlayer_BUSY 12
#define PIN_TEST A0
#define PIN_VOL_UP A1
#define PIN_VOL_DOWN A2
#define PIN_MODE_SEL A5
#define PIN_ARD_P2 2
#define PIN_ARD_P3 3

#define PIN_IDE_ACTIVE PIN_ARD_P2
#define PIN_FLP_DRIVE_SEL PIN_ARD_P2
#define PIN_FLP_STEP PIN_ARD_P3
#define PIN_FLP_DISK_CHANGE 5
#define PIN_FLP_MOTOR_EN 6
#define PIN_LED LED_BUILTIN

/* Volume values */
#define VOLUME_1 10
#define VOLUME_2 15
#define VOLUME_3 20
#define VOLUME_4 22
#define VOLUME_5 24
#define VOLUME_6 26
#define VOLUME_7 28
#define VOLUME_8 31

/* Strings for reuse */
#define APP_TITLE "NoiseMaker"
#define APP_VERSION "0.1"
const char STR_DONE[] PROGMEM  = "done!";
const char STR_ERROR_ARGUMENT[] PROGMEM = "argument format";
const char STR_ERROR_DFPLAYER[] PROGMEM = "DFPlayer ERROR ";

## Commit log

2022-10-18 Initial layout
    [NoiseMaker IDE.kicad_pcb, NoiseMaker IDE.sch]
2022-10-18 Add test button
    [NoiseMaker IDE.kicad_pcb, NoiseMaker IDE.sch]
2022-11-01 Tweak silkscreen and dimensions
    [NoiseMaker IDE.kicad_pcb, NoiseMaker IDE.sch]
2022-11-06 First attempt at sketch
    [NoiseMaker IDE.kicad_pcb, NoiseMaker IDE.sch]
2022-11-20 Add proper power connector and more switches
    [NoiseMaker IDE.kicad_pcb, NoiseMaker IDE.sch]
2022-11-20 Try to squash bug where it is stuck on
    [NoiseMaker.ino, commands.cpp, constants.h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]
2022-11-28 Rename project files
    [NoiseMaker IDE.kicad_pcb, NoiseMaker.kicad_pcb, NoiseMaker.sch]
2022-11-30 JP2 now THT jumper
    [NoiseMaker.kicad_pcb, NoiseMaker.sch]
2022-11-30 Account for two common passive buzzers
    [NoiseMaker.kicad_pcb, NoiseMaker.sch]
2022-11-30 Did it properly
    [NoiseMaker.kicad_pcb]
2022-12-01 Rename library
    [NoiseMaker.kicad_pcb, NoiseMaker.sch]
2022-12-31 Update README and tweak silkscreen
    [NoiseMaker.kicad_pcb, NoiseMaker.sch]

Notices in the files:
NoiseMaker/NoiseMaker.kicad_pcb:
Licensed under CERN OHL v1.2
